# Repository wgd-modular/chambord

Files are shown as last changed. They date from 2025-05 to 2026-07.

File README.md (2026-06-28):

# Chambord

Chambord is a eurorack module, using the RP2040 or 2350 to implement an
8-channel trigger-in drum sampler.

The 8 channels are laid out **top to bottom = channel 1 to 8**. Each channel
has a trigger input jack and a bicolor (red/green) LED. There is one encoder
(turn + press) and one CV input.

# How to use it

There are only two controls: **turn** the encoder and **press** the encoder.

## Turning the encoder

What turning does depends on the current "page". You step through the pages by
**short-pressing** the encoder:

```
press        press         press        press
SELECT  -->  SAMPLE  -->  VOLUME  -->  PITCH  --> (back to SELECT)
```

- **SELECT** (start here): turn to choose the channel you want to work on.
- **SAMPLE**: turn to change the sample on the selected channel. Each channel
  has 4 samples (banks A–D); turning steps between them.
- **VOLUME**: turn to change the volume of the selected channel.
- **PITCH**: turn to change the pitch of the selected channel.

A short press always advances to the next page and wraps back to SELECT.

## Reading the LEDs

While you're editing, only the **selected channel's** LED lights, colour-coded
by page (green = choosing a thing, amber = setting an amount):

| LED | Page |
|---|---|
| green steady | SELECT  (turn to pick the channel) |
| green blinking | SAMPLE  (turn to change the sample) |
| amber steady | VOLUME  (turn to change the volume) |
| amber blinking | PITCH (turn to change the pitch) |

You'll also hear sample/volume/pitch changes as you turn.

## Screensaver / trigger activity

When you haven't touched the encoder for about **10 seconds**, the row switches
to a trigger-activity display: every channel flashes **green** when it gets a
trigger. Touch the encoder and it goes back to showing what you're editing.
(This keeps trigger flashes from distracting you while you work.)

## CV input

**Long-press** the encoder (hold ~3/4 second) to assign the CV input to the
**volume** of the currently selected channel. Long-press again on the same
channel to turn CV off.

## Settings are saved

Your per-channel sample and pitch choices (and the CV assignment) are saved
automatically to flash a moment after you stop adjusting, and restored on the
next power-up. Saving only happens while nothing is sounding, so it never
interrupts playback.

## If the encoder turns the wrong way

Open `firmware/Pikobeats/Pikobeats.ino` and change `ENCODER_DIR` from `1` to
`-1` (near the top), then rebuild.

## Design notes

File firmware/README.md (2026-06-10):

# Firmware 

This directory contains a number of variant firmware and support files for Chambord.

# Status

10.06.2026 - The 'trippy' uf2 is built with an rp2350 (pi pico 2). The led lighting may not suit, file an issue :)

20.06.2025 - The current status is beta for Pikobeats. An initial uf2 is included for testing. Angular jungle set.

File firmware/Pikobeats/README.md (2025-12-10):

## piko beats

In order to render cleanly, using the timer driven method curently employed:
Pico2, optimize -O3, overclock to 276mHz

The samples are, still, prepared by the wav2header utility (windows, runs fine with wine64). The naming is a bit odd, still.

There are four sets, a, b, c, d each of which have 8 files. so it's a1-instrument ( descriptive text ). This should be improved.

a1-BD
b2-BD
c3-BD
d4-BD 

would yeild the bassdrum instruments on channel one.

A better naming would be something like
a-1
a-2
...
b-1
b-2
... etc.

This naming ordering would work fine with wav2header since the header in pikobeats just lists the samples in order, not by name.

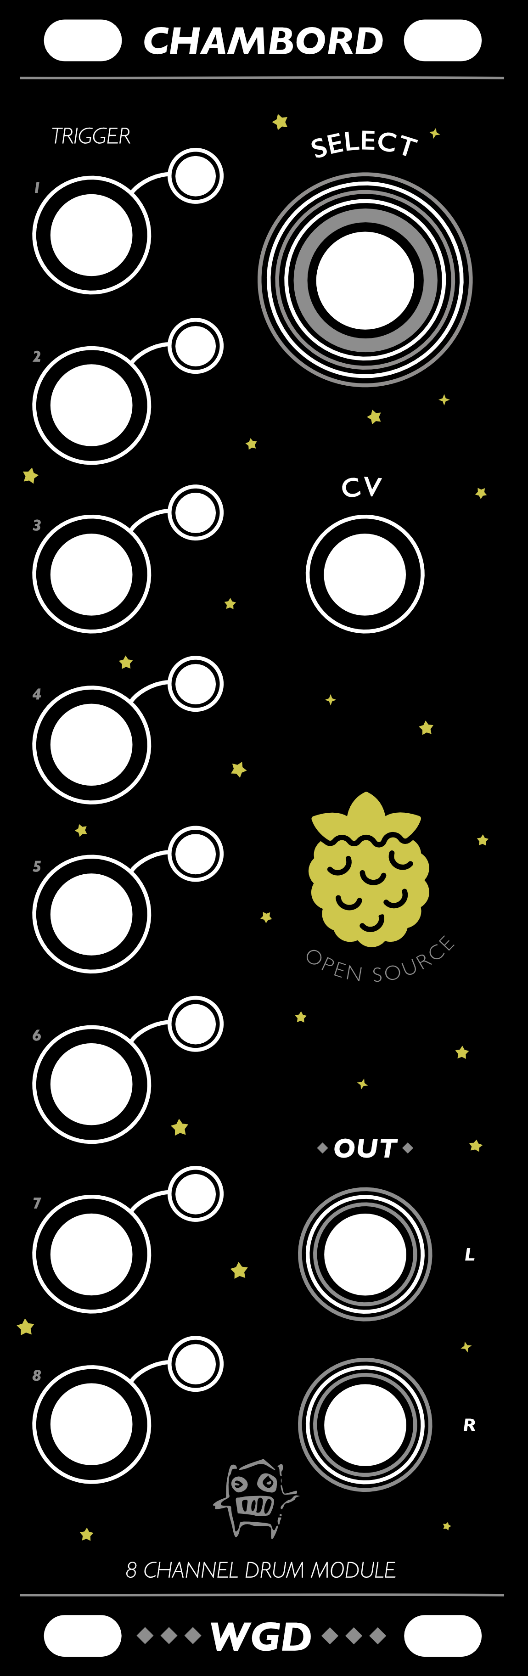
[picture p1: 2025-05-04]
design-resources/chambord.png

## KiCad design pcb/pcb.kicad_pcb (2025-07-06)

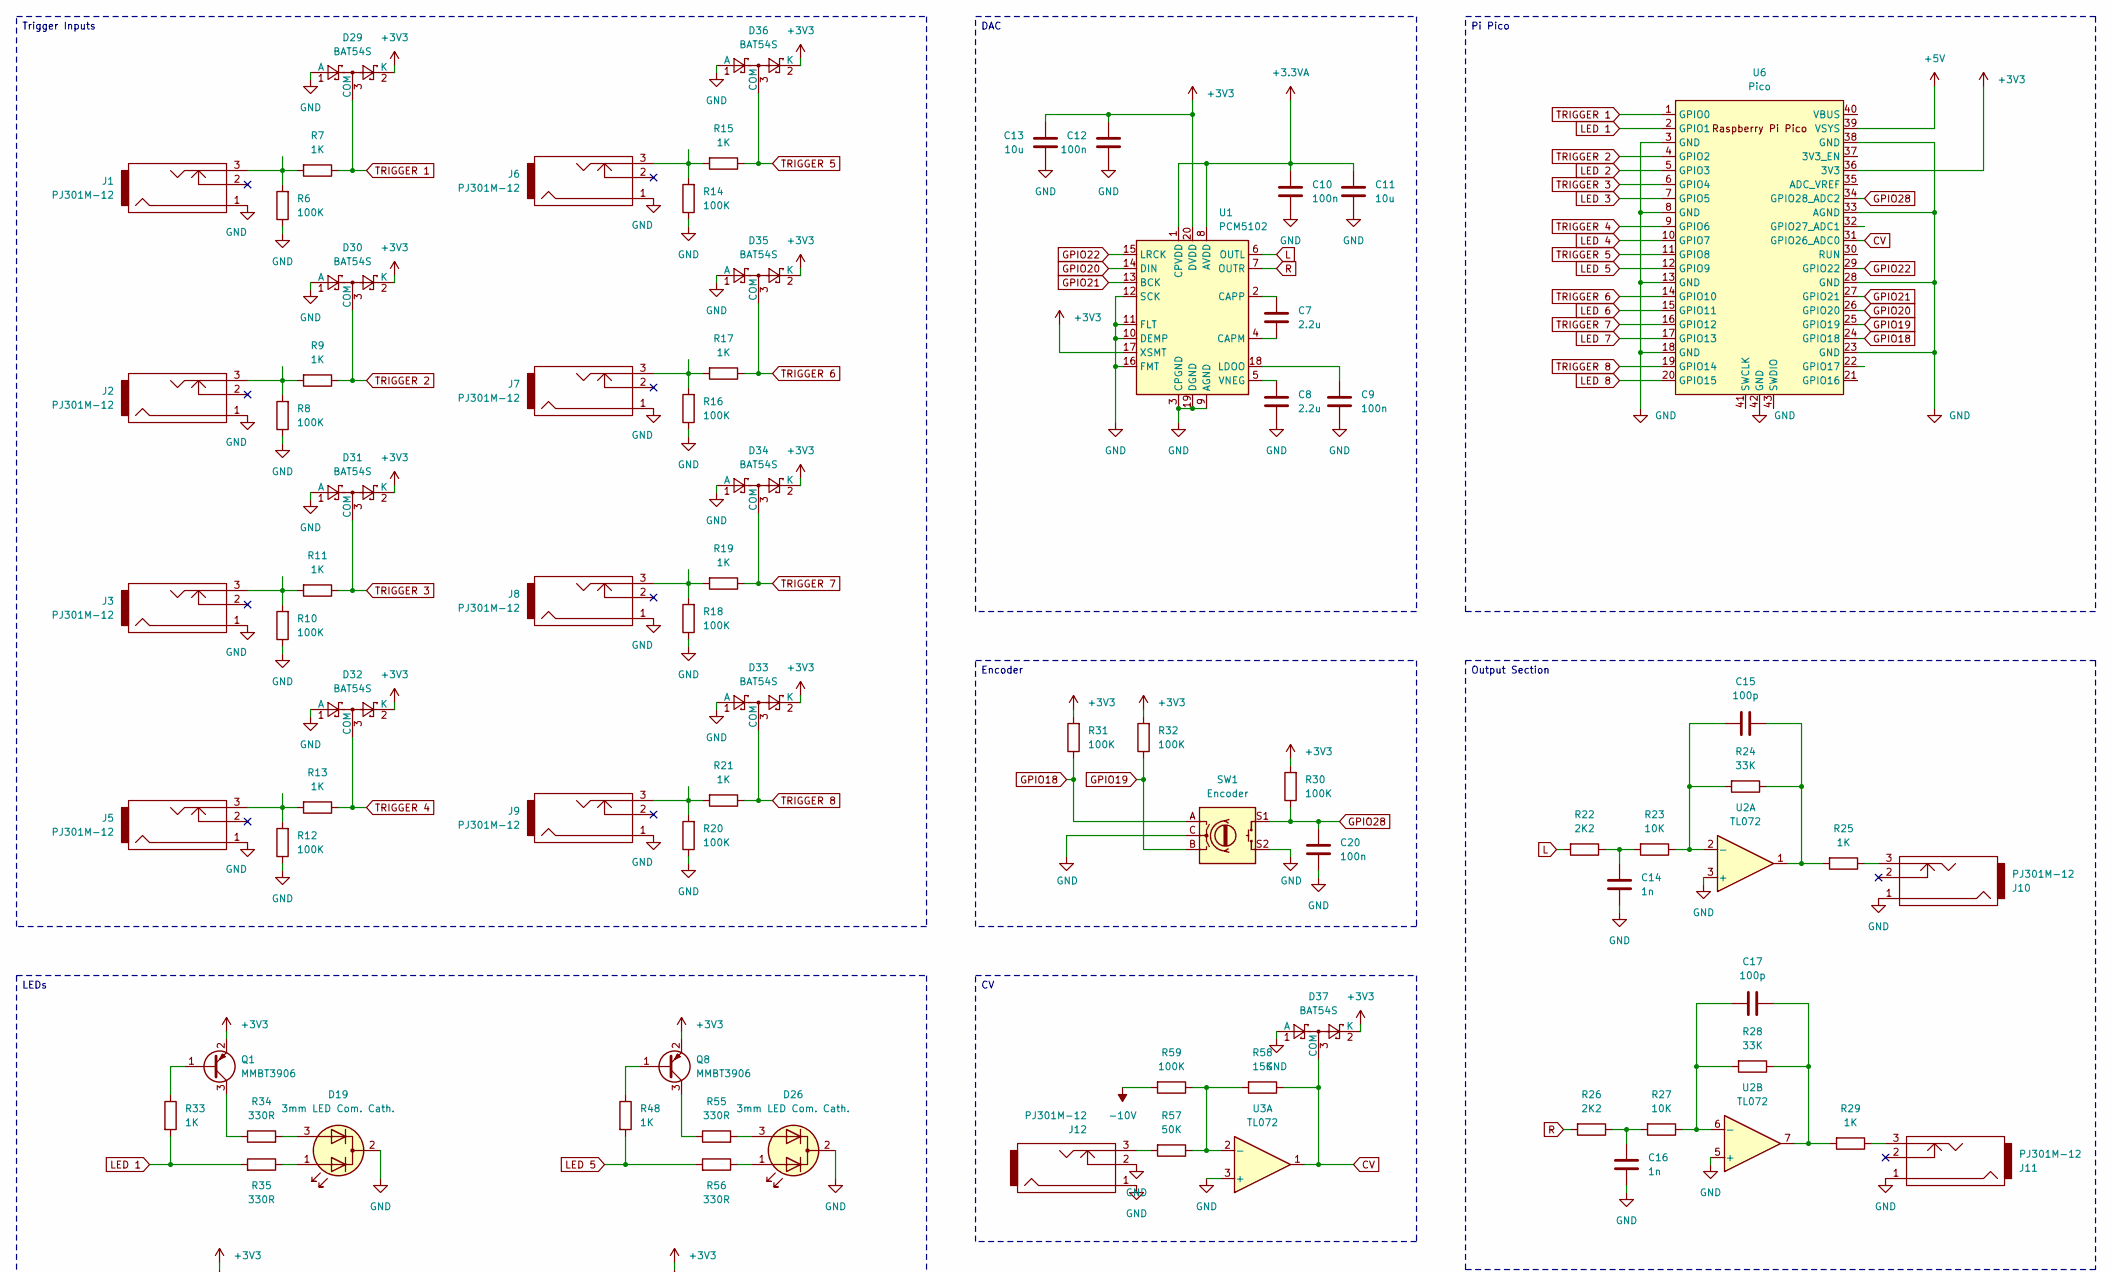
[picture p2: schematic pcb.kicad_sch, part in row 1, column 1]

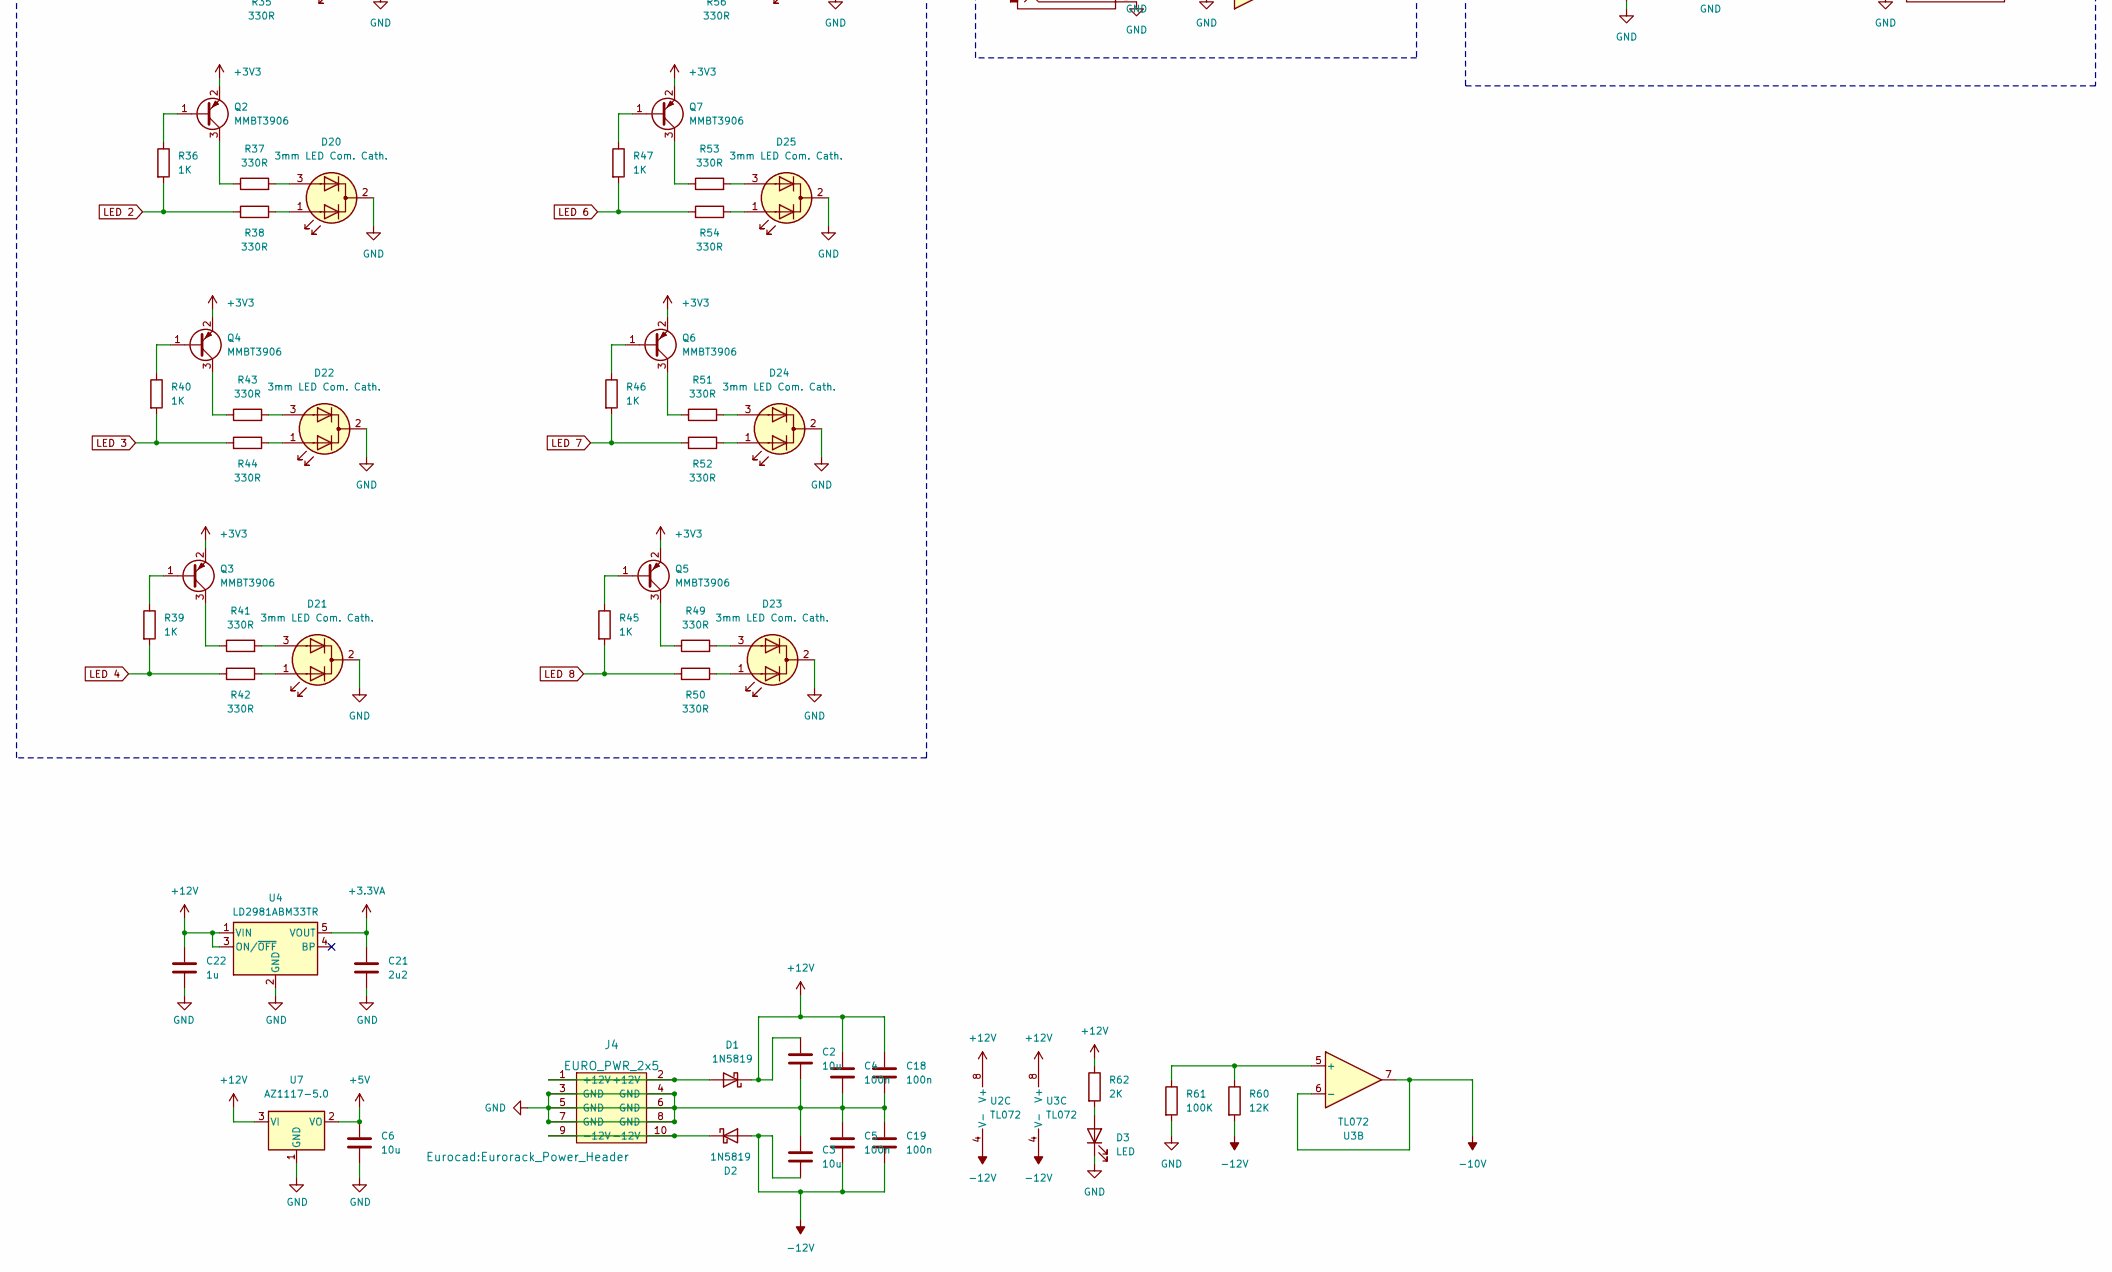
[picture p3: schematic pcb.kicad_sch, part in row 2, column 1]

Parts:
C2, C3, C6, C11, C13: 10u; C_0805_2012Metric
C4, C5, C9, C10, C12, C18, C19, C20: 100n; C_0603_1608Metric
C7, C8: 2.2u; C_0805_2012Metric
C14, C16: 1n; C_0603_1608Metric
C15, C17: 100p; C_0603_1608Metric
C21: 2u2; C_0805_2012Metric
C22: 1u; C_0805_2012Metric
D1, D2: 1N5819; D_SOD-123
D3: LED; LED_0603_1608Metric
D19, D20, D21, D22, D23, D24, D25, D26: 3mm LED Com. Cath.; LED_D3.0mm-3
D29, D30, D31, D32, D33, D34, D35, D36, D37: BAT54S; SOT-23; JLC C7420333
J1, J2, J3, J5, J6, J7, J8, J9, J10, J11, J12: PJ301M-12
J4: EURO_PWR_2x5; Eurorack_Power_Header
Q1, Q2, Q3, Q4, Q5, Q6, Q7, Q8: MMBT3906; SOT-23
R6, R8, R10, R12, R14, R16, R18, R20, R30, R31, R32, R59, R61: 100K; R_0603_1608Metric
R7, R9, R11, R13, R15, R17, R19, R21, R25, R29, R33, R36, R39, R40, R45, R46, R47, R48: 1K; R_0603_1608Metric
R22, R26: 2K2; R_0603_1608Metric
R23, R27: 10K; R_0603_1608Metric
R24, R28: 33K; R_0603_1608Metric
R34, R35, R37, R38, R41, R42, R43, R44, R49, R50, R51, R52, R53, R54, R55, R56: 330R; R_0603_1608Metric
R57: 50K; R_0603_1608Metric
R58: 15K; R_0603_1608Metric
R60: 12K; R_0603_1608Metric
R62: 2K; R_0603_1608Metric
SW1: Encoder; RotaryEncoder_Alps_EC11E-Switch_Vertical_H20mm
U1: PCM5102; TSSOP-20_4.4x6.5mm_P0.65mm
U2, U3: TL072; SOIC-8_3.9x4.9mm_P1.27mm
U4: LD2981ABM33TR; SOT-23-5
U6: Pico; RaspberryPi_Pico_Common_THT
U7: AZ1117-5.0; SOT-223-3_TabPin2

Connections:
+3.3VA: C10.1, C11.1, C21.1, U1.1 (CPVDD), U1.8 (AVDD), U4.5 (VOUT)
+3V3: C12.1, C13.1, D29.2 (K), D30.2 (K), D31.2 (K), D32.2 (K), D33.2 (K), D34.2 (K), D35.2 (K), D36.2 (K), D37.2 (K), Q1.2 (E), Q2.2 (E), Q3.2 (E), Q4.2 (E), Q5.2 (E), Q6.2 (E), Q7.2 (E), Q8.2 (E), R30.2, R31.2, R32.2, U1.17 (XSMT), U1.20 (DVDD), U6.36 (3V3)
+5V: C6.1, U6.39 (VSYS), U7.2 (VO)
+12V: C2.1, C4.1, C18.1, C22.1, D1.1 (K), R62.1, U2.8 (V+), U3.8 (V+), U4.1 (VIN), U4.3 (ON/~OFF), U7.3 (VI)
-10V: R59.2, U3.6 (-), U3.7
-12V: C3.2, C5.2, C19.2, D2.2 (A), R60.2, U2.4 (V-), U3.4 (V-)
CV: D37.3 (COM), R58.1, U3.1, U6.31 (GPIO26_ADC0)
GND: C2.2, C3.1, C4.2, C5.1, C6.2, C8.2, C9.2, C10.2, C11.2, C12.2, C13.2, C14.2, C16.2, C18.2, C19.1, C20.2, C21.2, C22.2, D3.1 (K), D19.2 (K), D20.2 (K), D21.2 (K), D22.2 (K), D23.2 (K), D24.2 (K), D25.2 (K), D26.2 (K), D29.1 (A), D30.1 (A), D31.1 (A), D32.1 (A), D33.1 (A), D34.1 (A), D35.1 (A), D36.1 (A), D37.1 (A), J1.1, J2.1, J3.1, J4.3 (GND), J4.4 (GND), J4.5 (GND), J4.6 (GND), J4.7 (GND), J4.8 (GND), J5.1, J6.1, J7.1, J8.1, J9.1, J10.1, J11.1, J12.1, J12.2, R6.1, R8.1, R10.1, R12.1, R14.1, R16.1, R18.1, R20.1, R61.2, SW1.C, SW1.S2, U1.3 (CPGND), U1.9 (AGND), U1.10 (DEMP), U1.11 (FLT), U1.12 (SCK), U1.16 (FMT), U1.19 (DGND), U2.3 (+), U2.5 (+), U3.3 (+), U4.2 (GND), U6.3 (GND), U6.8 (GND), U6.13 (GND), U6.18 (GND), U6.23 (GND), U6.28 (GND), U6.33 (AGND), U6.38 (GND), U6.42 (GND), U7.1 (GND)
GPIO18: R31.1, SW1.A, U6.24 (GPIO18)
GPIO19: R32.1, SW1.B, U6.25 (GPIO19)
GPIO20: U1.14 (DIN), U6.26 (GPIO20)
GPIO21: U1.13 (BCK), U6.27 (GPIO21)
GPIO22: U1.15 (LRCK), U6.29 (GPIO22)
GPIO28: C20.1, R30.1, SW1.S1, U6.34 (GPIO28_ADC2)
L: R22.2, U1.6 (OUTL)
LED 1: R33.2, R35.2, U6.2 (GPIO1)
LED 2: R36.2, R38.2, U6.5 (GPIO3)
LED 3: R40.2, R44.2, U6.7 (GPIO5)
LED 4: R39.2, R42.2, U6.10 (GPIO7)
LED 5: R48.2, R56.2, U6.12 (GPIO9)
LED 6: R47.2, R54.2, U6.15 (GPIO11)
LED 7: R46.2, R52.2, U6.17 (GPIO13)
LED 8: R45.2, R50.2, U6.20 (GPIO15)
unnamed: C14.1, R22.1, R23.2
unnamed: C15.2, R24.1, R25.2, U2.1
unnamed: C16.1, R26.1, R27.2
unnamed: C17.2, R28.1, R29.2, U2.7
unnamed: D1.2 (A), J4.1 (+12V), J4.2 (+12V)
unnamed: D2.1 (K), J4.9 (-12V), J4.10 (-12V)
unnamed: D3.2 (A), R62.2
unnamed: D19.1 (A1), R35.1
unnamed: D19.3 (A2), R34.2
unnamed: D20.1 (A1), R38.1
unnamed: D20.3 (A2), R37.2
unnamed: D21.1 (A1), R42.1
unnamed: D21.3 (A2), R41.2
unnamed: D22.1 (A1), R44.1
unnamed: D22.3 (A2), R43.2
unnamed: D23.1 (A1), R50.1
unnamed: D23.3 (A2), R49.2
unnamed: D24.1 (A1), R52.1
unnamed: D24.3 (A2), R51.2
unnamed: D25.1 (A1), R54.1
unnamed: D25.3 (A2), R53.2
unnamed: D26.1 (A1), R56.1
unnamed: D26.3 (A2), R55.2
unnamed: J1.3, R6.2, R7.2
unnamed: J2.3, R8.2, R9.2
unnamed: J3.3, R10.2, R11.2
unnamed: J5.3, R12.2, R13.2
unnamed: J6.3, R14.2, R15.2
unnamed: J7.3, R16.2, R17.2
unnamed: J8.3, R18.2, R19.2
unnamed: J9.3, R20.2, R21.2
unnamed: J10.3, R25.1
unnamed: J11.3, R29.1
unnamed: J12.3, R57.2
unnamed: Q1.1 (B), R33.1
unnamed: Q1.3 (C), R34.1
unnamed: Q2.1 (B), R36.1
unnamed: Q2.3 (C), R37.1
unnamed: Q3.1 (B), R39.1
unnamed: Q3.3 (C), R41.1
unnamed: Q4.1 (B), R40.1
unnamed: Q4.3 (C), R43.1
unnamed: Q5.1 (B), R45.1
unnamed: Q5.3 (C), R49.1
unnamed: Q6.1 (B), R46.1
unnamed: Q6.3 (C), R51.1
unnamed: Q7.1 (B), R47.1
unnamed: Q7.3 (C), R53.1
unnamed: Q8.1 (B), R48.1
unnamed: Q8.3 (C), R55.1
unnamed: C7.2, U1.4 (CAPM)
unnamed: C7.1, U1.2 (CAPP)
unnamed: C9.1, U1.18 (LDOO)
unnamed: C8.1, U1.5 (VNEG)
unnamed: C15.1, R23.1, R24.2, U2.2 (-)
unnamed: C17.1, R27.1, R28.2, U2.6 (-)
unnamed: R57.1, R58.2, R59.1, U3.2 (-)
unnamed: R60.1, R61.1, U3.5 (+)
R: R26.2, U1.7 (OUTR)
TRIGGER 1: D29.3 (COM), R7.1, U6.1 (GPIO0)
TRIGGER 2: D30.3 (COM), R9.1, U6.4 (GPIO2)
TRIGGER 3: D31.3 (COM), R11.1, U6.6 (GPIO4)
TRIGGER 4: D32.3 (COM), R13.1, U6.9 (GPIO6)
TRIGGER 5: D36.3 (COM), R15.1, U6.11 (GPIO8)
TRIGGER 6: D35.3 (COM), R17.1, U6.14 (GPIO10)
TRIGGER 7: D34.3 (COM), R19.1, U6.16 (GPIO12)
TRIGGER 8: D33.3 (COM), R21.1, U6.19 (GPIO14)

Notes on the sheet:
Encoder
DAC
LEDs
Pi Pico
Trigger Inputs
Output Section

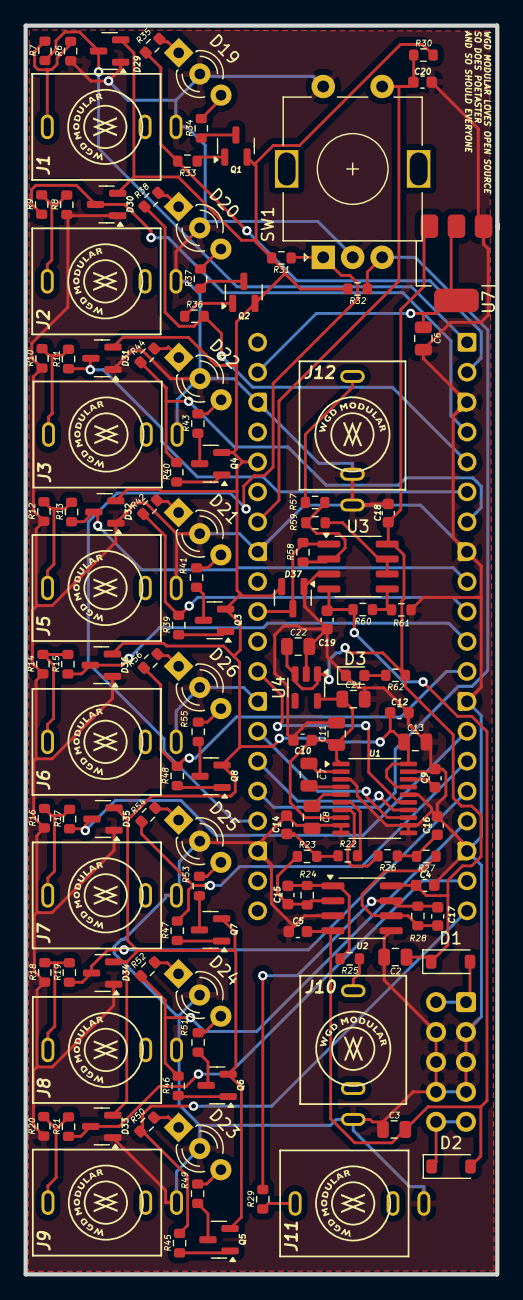
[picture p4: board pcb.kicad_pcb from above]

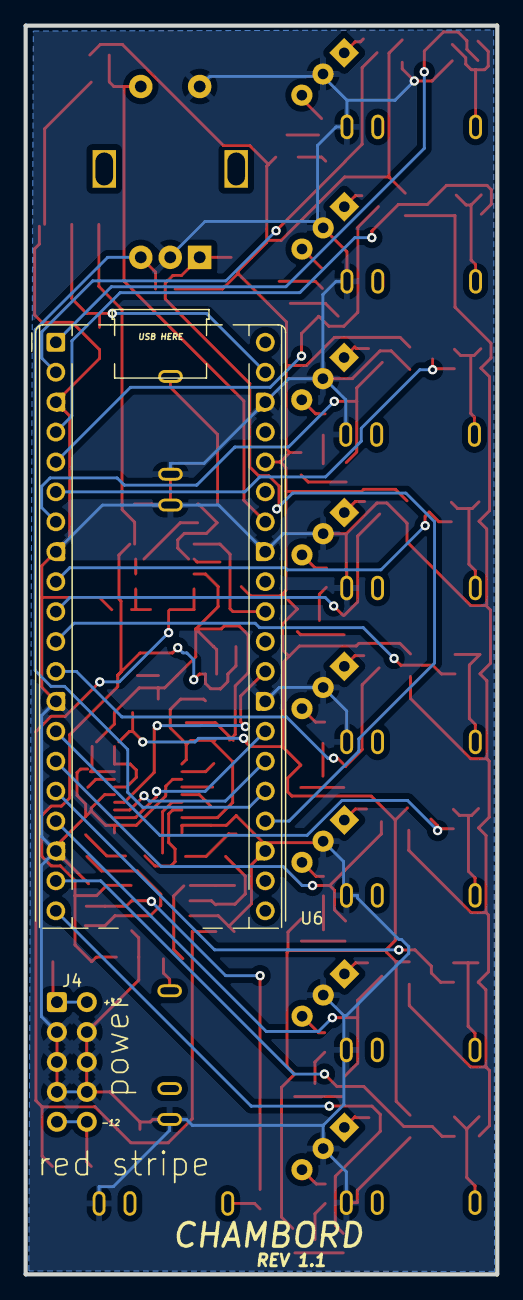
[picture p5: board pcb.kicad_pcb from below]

Board: 2 copper layers, 40.0 x 106.0 mm, 125 parts (2 on the bottom side), 90 nets.

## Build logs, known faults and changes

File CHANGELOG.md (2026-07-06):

# Changelog

## 1.0.0 (2026-07-01)

### Features

* rework audio engine, simplify UI, add CI ([d3c88b5](https://github.com/wgd-modular/chambord/commit/d3c88b5726d20f5539bd95611d42c632e766eb0f))
* rework audio engine, simplify UI, add CI ([da60962](https://github.com/wgd-modular/chambord/commit/da6096227d832539272b47c49966bcbeb733e541))

### Bug Fixes

* Allow rotational channel selection ([18fcced](https://github.com/wgd-modular/chambord/commit/18fccedee60266fa6a5453aa082c8b1f41a5744f))
* corrected uf2 ([98e2633](https://github.com/wgd-modular/chambord/commit/98e2633e7d3a1c4cf471b4a8414e017b1c8b5e8f))
* get all the basics running ([564b5db](https://github.com/wgd-modular/chambord/commit/564b5db0c58d85b13a0e121b2e7f20b510d59753))
* move DAC writes to 48khz timer and only do sample generation on request when dac has been writtern. ([0ea6d1c](https://github.com/wgd-modular/chambord/commit/0ea6d1c6be09060b37d975405fbccce7a9ee2cff))
* move encoder processing and remove contention on leds to remove noise ([00241a3](https://github.com/wgd-modular/chambord/commit/00241a3001df9c9cd52b4fd3415baddb6ffa9bd3))
* move jack in led signal to timer. cv also on slow timer. ([21f0c8b](https://github.com/wgd-modular/chambord/commit/21f0c8b7639766c76f8883b62c31836081725064))
* new uf2 with latest timer code ([514b767](https://github.com/wgd-modular/chambord/commit/514b7678cf0143d4c2cfdfc8f3cfe787f7a16f79))
* remove core idling since it can crash. ([1852d89](https://github.com/wgd-modular/chambord/commit/1852d89e810b191ad4a3e83d04a00b6cf68b015c))
* set to 44100 kHz for pitch correct play, up buffer lengths ([c2309d1](https://github.com/wgd-modular/chambord/commit/c2309d1a34663f6960478cda913241d967c42cab))

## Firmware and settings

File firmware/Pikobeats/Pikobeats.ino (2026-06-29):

/* Copyright 2025 Mark Washeim
  Author: Mark Washeim <blueprint@poetaster.de>

  This program is a derivative of one made by Rich Heslip, 2023,
  The euclidean bits are derivatives of code from bastl instruments.

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
  See http://creativecommons.org/licenses/MIT/ for more information.

  -----------------------------------------------------------------------------


  // sample player inspired by Jan Ostman's ESP8266 drum machine http://janostman.wordpress.com

  samples for beatbox from:
  giddster ( https://freesound.org/people/giddster/ )
  AlienXXX ( https://freesound.org/people/AlienXXX/

  The euclid code originates at:
  https://github.com/bastl-instruments/one-chip-modules/blob/master/EUCLID/EUCLID.ino

*/

bool debug = false;

#include <Arduino.h>
#include "stdio.h"
#include "pico/stdlib.h"
#include "hardware/gpio.h"
#include "hardware/sync.h"
#include "hardware/structs/ioqspi.h"
#include "hardware/structs/sio.h"

#include "io.h"
#include "euclid.h"
#include "filter.h"

#include <math.h>     // tanhf for the output soft-clip
#include <EEPROM.h>   // flash-backed settings persistence

// we have 8 voices that can play any sample when triggered
// this structure holds the settings for each voice
// 80s only to 20, jungle to 29
// we use a header per sample set
//
// Pick the sound kit at compile time. The CI builds one firmware per kit by
// passing e.g. -DCHAMBORD_KIT_80S ; locally, define one of these (or leave the
// default trippy). Each kit header defines voice_t/voice[] and pulls in its
// own samples. ("not ready" kits world/beatbox/bbox have no sample data.)
#if   defined(CHAMBORD_KIT_80S)
  #include "80s.h"
#elif defined(CHAMBORD_KIT_ANGULARJ)
  #include "angularj.h"
#elif defined(CHAMBORD_KIT_MIX)
  #include "mix.h"
#elif defined(CHAMBORD_KIT_TEKKE)
  #include "tekke.h"
#elif defined(CHAMBORD_KIT_ACOUSTIC3)
  #include "acoustic3.h"
#else
  #include "trippy.h"
#endif
// we can have an arbitrary number of samples but you will run out of memory at some point
// sound sample files are 22khz 16 bit signed PCM format - see the sample include files for examples
// you can change the sample rate to whatever you want but most testing was done at 22khz. 44khz probably works but not much testing was done
// use the wave2header22khz.exe utility to automagically batch convert all the .wav files in a directory into the required header files
// put your 22khz or 44khz PCM wav files in a sample subdirectory with a copy of the utility, run the utility and it will generate all the required header files
// wave2header creates a header file containing the signed PCM values for each sample - note that it may change the name of the file if required to make it "c friendly"
// wave2header also creates sampledefs.h which is an array of structures containing information about each sample file
// the samples are arranged in alphabetical order to facilitate grouping samples by name - you can manually edit this file to change the order of the samples as needed
// sampledefs.h contains other information not used by this program e.g. the name of the sample file - I wrote it for another project
// wave2header also creates "samples.h" which #includes all the generated header files


#define NUM_SAMPLES (sizeof(sample)/sizeof(sample_t))

// What turning the encoder does. Press the encoder to step through these
// for the currently selected channel: select -> sample -> volume -> pitch.
enum {
  MODE_SELECT = 0, // turn = choose channel (1-8)
  MODE_SAMPLE,     // turn = change the sample of the selected channel
  MODE_VOLUME,     // turn = change the volume of the selected channel
  MODE_PITCH,      // turn = change the pitch of the selected channel
  MODE_COUNT
};

int display_mode = MODE_SELECT;

// Encoder direction. 1 = normal, -1 = inverted. The CI builds both variants by
// passing -DCHAMBORD_ENC_DIR=... ; to change it locally edit the default below.
#ifndef CHAMBORD_ENC_DIR
#define CHAMBORD_ENC_DIR 1
#endif
const int ENCODER_DIR = CHAMBORD_ENC_DIR;

// on the long ec11 these are swapped A 19, B 18
const int encoderA_pin = 18;
const int encoderB_pin = 19;
const int encoderSW_pin = 28;

#define DOUBLE_CLICK_THRESHOLD 400 
// encoder
#include <RotaryEncoder.h>
RotaryEncoder encoder(encoderB_pin, encoderA_pin, RotaryEncoder::LatchMode::FOUR3);

void __not_in_flash_func(checkEncoderPosition)() {
  encoder.tick();   // call tick() to check the state.
}

// DAC code, approach from mozzi

#include <I2S.h>
// GPIO pin numbers
#define pBCLK 21
#define pWS (pBCLK+1)
#define pDOUT 20

I2S DAC(OUTPUT);

static void startAudio() {
  DAC.setBCLK(pBCLK);
  DAC.setDATA(pDOUT);
  DAC.setBitsPerSample(16);
  DAC.setBuffers(4, 256, 0);
  DAC.begin(44100);
}

static void stopAudio() {
  DAC.end();
}
inline bool canBufferAudioOutput() {
  return (DAC.availableForWrite());
}

// these are irq timers for handling led signals
#include "timers.h"



// encoder button
#include <Bounce2.h>
Bounce2::Button enc_button = Bounce2::Button();

// additions
#include <Wire.h>

volatile int clk_display;
uint32_t clk_sync_last;

// input clk tracking
volatile int clk_state_last; // track the CLOCKIN pin state.

int clk_state = 0;
int clk_hits = 0;
uint32_t clk_sync_ms = 0;
bool sync = false; // used to detect if we have input sync


// begin hardware definitions
const int key_pins[] = { 0, 2, 4, 6, 8, 10, 12, 14 };
const int led_pins[] = { 1, 3, 5, 7, 9, 11, 13, 15 };


// variables for UI state management
int encoder_pos_last = 0;
int encoder_delta = 0;
uint32_t encoder_push_millis;
uint32_t step_push_millis;

// currently not used
int step_push = -1;
bool step_edited = false;
char seq_info[11];  // 10 chars + nul FIXME

bool encoder_held = false;

uint8_t display_repeats = 0;
uint8_t display_vol = 100;
uint8_t display_pitch = 50;
String display_pat;


// END additions

// from pikocore filter
uint8_t filter_fc = LPF_MAX + 10;
uint8_t hpf_fc = 0;
uint8_t filter_q = 0;

int16_t CV_last;

//#define MONITOR_CPU  // define to monitor Core 2 CPU usage on pin CPU_USE

// last time btn_one release
unsigned long btnOneLastTime;
int cv_track = 42; // used to assign a track CV modulation set out of bounds to start


// sample and debounce
// scan input jacks
bool scanbuttons(void)
{
  bool pressed;
  for (int i = 0; i < NUM_BUTTONS; ++i) {
    switch (i) { // sample gate inputs
      case 0:
        pressed = digitalRead(BUTTON0); // active low key inputs
        break;
      case 1:
        pressed = digitalRead(BUTTON1);
        break;
      case 2:
        pressed = digitalRead(BUTTON2);
        break;
      case 3:
        pressed = digitalRead(BUTTON3);
        break;
      case 4:
        pressed = digitalRead(BUTTON4);
        break;
      case 5:
        pressed = digitalRead(BUTTON5);
        break;
      case 6:
        pressed = digitalRead(BUTTON6);
        break;
      case 7:
        pressed = digitalRead(BUTTON7);
        break;
    }

    if (pressed) {
      if (debouncecnt[i] <= 3) ++debouncecnt[i];
      if (debouncecnt[i] == 2) { // trigger on second sample of key active
        button[i] = 1;
      }
    }
    else {
      debouncecnt[i] = 0;
      button[i] = 0;
    }
  }
  if (pressed) return true;
  else return false;
}


// include here to avoid forward references - I'm lazy :)
// this is the main class for generating output samples using the internal sequencer.

#include "seq.h"

// ---------------------------------------------------------------------------
// Audio mixing: precomputed per-voice gain + attack ramp (anti-click)
// ---------------------------------------------------------------------------
#define RAMP_LEN 48                 // ~1.1ms attack at 44.1kHz to kill retrigger clicks
int32_t  voice_gain[NTRACKS];       // Q15 gain (level/1000) precomputed so the mix loop has no divide
uint16_t voice_ramp[NTRACKS];       // attack ramp counter per track, counts up to RAMP_LEN

// set a track level (0-1000) and recompute its Q15 mix gain
inline void setLevel(int track, int level) {
  if (level < 0) level = 0;
  if (level > 1000) level = 1000;
  voice[track].level = level;
  voice_gain[track] = ((int32_t)level * 32768) / 1000;
}

// ---------------------------------------------------------------------------
// Settings persistence to flash (survives power cycle)
// stored: per-track sample + pitch, plus CV/selected track
// ---------------------------------------------------------------------------
#define EE_MAGIC 0xB4
#define EE_SIZE  256
struct persist_t {
  uint8_t  magic;
  uint8_t  cv_track;
  uint8_t  current_track;
  int16_t  sample[NTRACKS];
  uint16_t incr[NTRACKS];
  int16_t  level[NTRACKS];
};

bool     settings_dirty = false;
uint32_t settings_change_ms = 0;
inline void markDirty() { settings_dirty = true; settings_change_ms = millis(); }

void loadSettings() {
  persist_t p;
  EEPROM.get(0, p);
  if (p.magic != EE_MAGIC) return;            // nothing valid stored yet
  cv_track = p.cv_track;
  current_track = p.current_track % NTRACKS;
  for (int t = 0; t < NTRACKS; ++t) {
    if (p.sample[t] >= 0 && p.sample[t] < (int)NUM_SAMPLES) voice[t].sample = p.sample[t];
    voice[t].sampleincrement = constrain(p.incr[t], 2048, 8192);
    setLevel(t, p.level[t]);
  }
}

void saveSettings() {
  persist_t p;
  p.magic = EE_MAGIC;
  p.cv_track = cv_track;
  p.current_track = current_track;
  for (int t = 0; t < NTRACKS; ++t) {
    p.sample[t] = voice[t].sample;
    p.incr[t]   = voice[t].sampleincrement;
    p.level[t]  = voice[t].level;
  }
  EEPROM.put(0, p);
  EEPROM.commit();   // idles core1 internally during the flash erase/program
}

// ---------------------------------------------------------------------------
// Unified LED feedback engine
// Each LED is a single GPIO over a dual-colour part: GPIO low = red (floor),
// high = green, and a duty cycle in between = amber. ledRender() does software
// PWM from led_duty[]; updateUI() sets led_duty[] from the current UI state.
// ---------------------------------------------------------------------------
#define LED_LEVELS 8        // PWM steps -> 1ms tick gives ~125Hz refresh
#define LED_RED    0        // GPIO mostly low  -> red (also the idle floor colour)
#define LED_AMBER  4        // ~50% duty        -> amber
#define LED_GREEN  8        // GPIO high        -> green

volatile uint8_t led_duty[8] = {0};
volatile uint8_t led_phase = 0;

// software PWM, called every 1ms from the ISR timer (kept in RAM so it never
// waits on the flash bus that the audio core is reading samples from)
void __not_in_flash_func(ledRender)() {
  uint8_t ph = led_phase;
  for (int i = 0; i < 8; ++i) {
    digitalWrite(led[i], (led_duty[i] > ph) ? HIGH : LOW);
  }
  led_phase = (ph + 1) % LED_LEVELS;
}

// When the encoder hasn't been touched for this long, the row turns into a
// trigger-activity display ("screensaver"). While you ARE editing, the row
// shows only the selected channel's page so nothing distracts you.
#define SCREENSAVER_MS 3000
uint32_t ui_activity_ms = 0;

// Recompute per-channel LED colours. While editing, feedback lives only on the
// selected channel's own LED, colour-coded by page (green = choosing a thing,
// amber = setting an amount):
//   green steady   = SELECT  (turn to pick the channel)
//   green blinking = SAMPLE  (turn to change the sample)
//   amber steady   = VOLUME  (turn to change the volume)
//   amber blinking = PITCH   (turn to change the pitch)
// After SCREENSAVER_MS idle, every channel flashes green on a trigger instead.
// Throttled by the caller (~5ms) so it doesn't hog the flash bus.
void updateUI() {
  uint32_t now = millis();
  bool blink = (now / 150) & 1; // ~3 Hz
  bool screensaver = (now - ui_activity_ms) > SCREENSAVER_MS;

  for (int i = 0; i < 8; ++i) {
    uint8_t d = LED_RED; // idle floor

    if (screensaver) {
      if (voice[i].isPlaying) d = LED_GREEN;          // trigger-activity display
    } else if (i == current_track) {
      switch (display_mode) {
        case MODE_SELECT: d = LED_GREEN;                  break; // green steady
        case MODE_SAMPLE: d = blink ? LED_GREEN : LED_RED; break; // green blink
        case MODE_VOLUME: d = LED_AMBER;                  break; // amber steady
        case MODE_PITCH:  d = blink ? LED_AMBER : LED_RED; break; // amber blink
      }
    }
    led_duty[i] = d;
  }
}

#define DISPLAY_TIME 2000 // time in ms to display numbers on LEDS
int32_t display_timer;

// show a number in binary on the LEDs
void display_value(int16_t value) {
  for (int i = 7; i >= 0; i--) { // NOPE + 1 can loop this way because port assignments are sequential
    digitalWrite(led[i], value & 1);
    value = value >> 1;
  }
  display_timer = millis();
}

// rotate trigger pattern
uint16_t rightRotate(int shift, uint16_t value, uint8_t pattern_length) {
  uint16_t mask = ((1 << pattern_length) - 1);
  value &= mask;
  return ((value >> shift) | (value << (pattern_length - shift))) & mask;
}



// main core setup
void setup() {
  // set clock speed as in picokore
  //set_sys_clock_khz(264000, true); don't do this :)

  if (debug) Serial.begin(57600);

  // setup timers
  if (ITimer3.attachInterruptInterval(HW_TIMER_INTERVAL_MS * 1000, TimerHandler)) {
    if (debug) Serial.print(F("Starting ITimer1 OK, millis() = "));
    if (debug) Serial.println(millis());
    timersUp = true;
  } else {
    if (debug) Serial.println(F("Can't set ITimer1. Select another freq. or timer"));
    timersUp = false;
  }
  analogReadResolution(10);

  // Audio is rendered free-running on core1 and paced by the I2S DMA buffer
  // (DAC.write blocks when full), so no dedicated audio-rate timer is needed.

  // single LED software-PWM renderer (replaces the old b2/b5/b7/b10 handlers)
  ISR_timer.setInterval(1L, ledRender);


  if (debug) Serial.flush();


  // ENCODER
  pinMode(encoderA_pin, INPUT_PULLUP);
  pinMode(encoderB_pin, INPUT_PULLUP);
  attachInterrupt(digitalPinToInterrupt(encoderA_pin), checkEncoderPosition, CHANGE);
  attachInterrupt(digitalPinToInterrupt(encoderB_pin), checkEncoderPosition, CHANGE);
  // Encoder button
  
  enc_button.attach( SHIFTBUTTON, INPUT ); // USE EXTERNAL PULL-UP
  enc_button.interval(5); // 5ms debounce
  enc_button.setPressedState(LOW);

#ifdef MONITOR_CPU
  pinMode(CPU_USE, OUTPUT); // for monitoring CPU usage
#endif

  pinMode(BUTTON0, INPUT); // jack inputs
  pinMode(BUTTON1, INPUT);
  pinMode(BUTTON2, INPUT);
  pinMode(BUTTON3, INPUT);
  pinMode(BUTTON4, INPUT);
  pinMode(BUTTON5, INPUT);
  pinMode(BUTTON6, INPUT);
  pinMode(BUTTON7, INPUT);

  pinMode(LED0, OUTPUT);
  pinMode(LED1, OUTPUT);
  pinMode(LED2, OUTPUT);
  pinMode(LED3, OUTPUT);
  pinMode(LED4, OUTPUT);
  pinMode(LED5, OUTPUT);
  pinMode(LED6, OUTPUT);
  pinMode(LED7, OUTPUT);

  //pinMode(CLOCKOUT, OUTPUT);
  //pinMode(CLOCKIN, INPUT_PULLUP);

  pinMode(23, OUTPUT); // thi is to switch to PWM for power to avoid ripple noise
  digitalWrite(23, HIGH);


  //display_value(NUM_SAMPLES); // show number of samples on the display

  // init per-voice mix gains and ramps, then restore saved settings from flash
  for (int t = 0; t < NTRACKS; ++t) {
    setLevel(t, voice[t].level);
    voice_ramp[t] = RAMP_LEN;   // not ramping until first trigger
  }
  EEPROM.begin(EE_SIZE);
  loadSettings();

  startAudio();

}



// main core handles UI
void loop() {

  // timer
  uint32_t now = millis();
  scanbuttons(); // actually jack inputs

  // update the channel & play sample
  for (int i = 0; i < NTRACKS; ++i) { // scan all the trigger inputs (not the encoder button)
    if (button[i]) {
      //digitalWrite(led[i], 1); // we're doing the leds in timers.h
      voice[i].sampleindex = 0; // trigger sample for this track
      voice[i].isPlaying = true;
      voice_ramp[i] = 0; // restart attack ramp -> click-free retrigger
    }
  }

  encoder.tick();

  int encoder_pos = encoder.getPosition();
  if ( (encoder_pos != encoder_pos_last )) {
    encoder_delta = (encoder_pos - encoder_pos_last) * ENCODER_DIR;
  }

  // update encoder button state
  enc_button.update();

  // led updates on timer


  // use encoder and button
  if (encoder_delta) {
    ui_activity_ms = now; // wake the display out of screensaver

    // MODE_SELECT: turn to choose which channel (1-8) you're working on
    if ( display_mode == MODE_SELECT && ! enc_button.pressed() )  {
      // +8 keeps us in positive range for the modulo
      current_track = (current_track + encoder_delta + 8) % 8;
      // NOTE: selecting a channel no longer changes its volume (that caused clicks)
    }

    // MODE_SAMPLE: turn to change the sample of the selected channel
    if ( display_mode == MODE_SAMPLE ) {
      int result = voice[current_track].sample + (encoder_delta > 0 ? 8 : -8);
      if (debug) Serial.println(result);
      if (result >= 0 && result <= NUM_SAMPLES - 1) {
        voice[current_track].sample = result;
        voice_ramp[current_track] = 0; // re-attack to soften the swap if it's ringing
        markDirty();
      }
    }

    // MODE_VOLUME: turn to change the volume of the selected channel
    if ( display_mode == MODE_VOLUME ) {
      setLevel(current_track, voice[current_track].level + encoder_delta * 50);
      markDirty();
    }

    // MODE_PITCH: turn to change the pitch of the selected channel.
    // Unity = 4096 (1:12 fixed point); 2048..8192 spans one octave down..up.
    // 128/detent (~2.6 detents per semitone) - the old step of 10 was so tiny
    // (~0.24%/detent) that it felt like nothing happened.
    if ( display_mode == MODE_PITCH ) {
      int pitch_change = voice[current_track].sampleincrement + (encoder_delta * 128);
      pitch_change = constrain(pitch_change, 2048, 8192); // constrain returns a value, must assign
      pitch_change &= ~1;                                 // keep even -> no click
      voice[current_track].sampleincrement = pitch_change;
      markDirty();
    }
  }

  /// only set new pos last after use of the delta
  encoder_pos_last = encoder_pos;
  encoder_delta = 0;  // we've used it


  // Encoder button:
  //   short press  -> step turn-function: select -> pitch -> sample -> select
  //   long press (>700ms) -> toggle CV control of the selected channel's volume
  if (enc_button.rose()) {
    ui_activity_ms = now;
    btnOneLastTime = enc_button.previousDuration();
    if (btnOneLastTime > 700) {
      cv_track = (cv_track == current_track) ? 99 : current_track; // 99 = CV off
      markDirty();
    }
  } else if (enc_button.pressed() ) {
    ui_activity_ms = now;
    encoder_push_millis = now;
    display_mode = display_mode + 1;
    if ( display_mode >= MODE_COUNT) display_mode = MODE_SELECT;
  } else {
    encoder_push_millis = 0;
    encoder_held = false;
  }

  // CV input modulates the volume of the assigned channel (if any).
  // CV-driven volume is intentionally NOT persisted (would wear flash).
  if (cv_track < NTRACKS) {
    int16_t cvv = CV;
    if (cvv != CV_last) {
      setLevel(cv_track, constrain(cvv, 0, 350));
      CV_last = cvv;
    }
  }

  // Refresh UI + sample CV at ~200Hz (throttled so core0 doesn't starve the
  // audio core's flash reads -> this was a source of pops while turning).
  static uint32_t ui_last = 0;
  if (now - ui_last >= 5) {
    ui_last = now;
    CV = analogRead(A0);
    updateUI();
  }

  // Debounced auto-save, but only while nothing is sounding, so the brief
  // audio pause during the flash write happens in silence (no pop).
  if (settings_dirty && (now - settings_change_ms) > 1500) {
    bool anyPlaying = false;
    for (int i = 0; i < NTRACKS; ++i) if (voice[i].isPlaying) { anyPlaying = true; break; }
    if (!anyPlaying ) {
      saveSettings();
      settings_dirty = false;
    }
  }



  /*
     These are from the original scarp peakobeats
      if ( (encoder_pos != encoder_pos_last ) && display_mode == 1 ) {
        //uint8_t re = seq[i].trigger->getRepeats() + encoder_delta;
        seq[i].trigger->setRepeats(encoder_delta);
        display_repeats = seq[i].trigger->getRepeats();

      }
      // change volume on pot 1
      if (!potlock[1] && display_mode == 0) {
        int16_t level = (int16_t)(map(potvalue[1], POT_MIN, POT_MAX, 0, 1000));
        voice[current_track].level = level;
        display_vol = level / 10;
        // change sample volume level if pot has moved enough
      }
      if (!potlock[0] && display_mode == 1 ) {
        //filter_fc = potvalue[0] * (LPF_MAX + 10) / 4096;
        seq[i].fills = map(potvalue[0], POT_MIN, POT_MAX, 0, 16);
        seq[i].trigger->generateRandomSequence(seq[i].fills, 15);
        display_pat = (String) seq[i].trigger->textSequence;
      }

      // set track euclidean triggers if either pot has moved enough
      if (!potlock[1] && ! button[8] && display_mode == 1) {
        seq[i].fills = map(potvalue[1], POT_MIN, POT_MAX, 0, 16);
        seq[i].trigger->generateSequence(seq[i].fills, 15);
        seq[i].trigger->resetSequence(); // set to 0
        display_pat = (String) seq[i].trigger->textSequence;

      }
      //trig/retrig play
      if ( display_mode == 2 && i < 8 && voice[current_track].isPlaying == false) {
        voice[current_track].sampleindex = 0; // trigger sample for this track
        voice[current_track].isPlaying = true;
      }
  */
}



// second core setup
// second core dedicated to sample processing
void setup1() {
  delay (2000); // wait for main core to start up perhipherals
}
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

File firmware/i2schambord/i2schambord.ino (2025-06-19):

/*
  This example generates a square wave based tone at a specified frequency
  and sample rate. Then outputs the data using the I2S interface to a
  MAX08357 I2S Amp Breakout board.

  created 17 November 2016
  by Sandeep Mistry
  modified for RP2040 by Earle F. Philhower, III <earlephilhower@yahoo.com>


    bool setBCLK(pin_size_t pin);
    - This assigns two adjacent pins - the pin after this one (one greater)
      is the WS (word select) signal, which toggles before the sample for
      each channel is sent

    bool setDATA(pin_size_t pin);
    - Sets the DOUT pin, can be any valid GPIO pin
*/

#include <I2S.h>

// GPIO pin numbers
#define pBCLK 21
#define pWS (pBCLK+1)
#define pDOUT 20

I2S i2s(OUTPUT);

static void startAudio() {

  i2s.setBCLK(pBCLK);
  i2s.setDATA(pDOUT);
  i2s.setBitsPerSample(16);
  i2s.begin(48000);
}

static void stopAudio(){
  i2s.end();
}
inline bool canBufferAudioOutput() {
  return (i2s.availableForWrite());
}

const int frequency = 440; // frequency of square wave in Hz
const int amplitude = 500; // amplitude of square wave
const int sampleRate = 48000; // minimum for UDA1334A

const int halfWavelength = (sampleRate / frequency); // half wavelength of square wave

int16_t sample = amplitude; // current sample value
int count = 0;

void setup() {
  pinMode(3, OUTPUT);
  digitalWrite(3, 1);

  Serial.begin(115200);
  Serial.println("I2S simple tone");
  
  startAudio();
  

}

void loop() {
  if (count % halfWavelength == 0) {
    // invert the sample every half wavelength count multiple to generate square wave
    sample = -1 * sample;
    digitalWrite(3, 0);
  } else {
    digitalWrite(3,1);
  }

  // write the same sample twice, once for left and once for the right channel
  i2s.write(sample);
  i2s.write(sample);

  // increment the counter for the next sample
  count++;
}

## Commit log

2025-04-16 Start schematic
    [pcb.kicad_sch]
2025-04-17 Continue schematic
    [pcb.kicad_sch]
2025-04-17 Add LEDs, Triggers and CV in (closes #1)
    [pcb.kicad_sch]
2025-04-19 Replace OP-Amp and add GPIO input protection diodes for eventual clamping
    [pcb.kicad_sch]
2025-05-01 Implement feedback from Niek
    [pcb.kicad_sch]
2025-05-04 Rev 1
    [panel.kicad_pcb, pcb.kicad_pcb, pcb.kicad_sch]
2025-05-04 Move U7
    [pcb.kicad_pcb]
2025-06-13 Fix missing XSMT connection to 3V3
    [pcb.kicad_pcb, pcb.kicad_sch]
2025-06-19 Add: test firmware for leds and i2s
2025-06-19 Add: timers
2025-06-19 Fix: get all the basics running
    [Pikobeats.ino]
2025-06-19 Debug: still using the leds to test some state.
2025-06-20 Fix. both pitch shift and sample select working
    [Pikobeats.ino]
2025-06-20 Fix: remove core idling since it can crash.
    [Pikobeats.ino]
2025-06-20 Fix: move encoder processing and remove contention on leds to remove noise
    [Pikobeats.ino]
2025-06-20 Add: cv input to volume of current track, mode 0
2025-06-20 Fix: move jack in led signal to timer. cv also on slow timer.
    [Pikobeats.ino]
2025-06-26 Fix 3V3 missing on DAC and use additional LDO for 3V3 on DAC
    [pcb.kicad_pcb, pcb.kicad_sch]
2025-06-28 Fix: move DAC writes to 48khz timer and only do sample generation on request when dac has been writtern.
2025-06-28 Fix: new uf2 with latest timer code
2025-07-06 Rev 1.1
    [panel.kicad_pcb, pcb.kicad_pcb]
2025-07-23 Refactor: red/green duty cycles (red on by default, flipped in software).
    [Pikobeats.ino]
2025-07-24 Refactor: move led indicators to current channel
2025-07-29 fix: Allow rotational channel selection
    [Pikobeats.ino]
2025-12-08 Update: edited samples, all 16bit, 44khz
2025-12-10 Fix: set to 44100 kHz for pitch correct play, up buffer lengths
    [Pikobeats.ino]
2026-06-27 feat: rework audio engine, simplify UI, add CI
    Audio:
    - render on core1 paced by the I2S DMA buffer instead of a timer ISR
    - soft-clip the mix for headroom, precompute per-voice gain, ramp attacks
    - fix constrain() no-ops, the interpolation read past the sample end and
    the off-by-one LED and trigger loop bounds
    UI:
    - four encoder pages: select, sample, volume, pitch
    - per-channel LED colours with a 10s trigger-activity screensaver
    - save sample, pitch, volume and CV assignment to flash
    - encoder direction and sound kit are build-time options
    CI:
    - matrix build of every kit for normal and reversed encoders
    - release-please for versioning and releases
    [Pikobeats.ino]
2026-06-29 [Fix] remove the unused running average code since it is not applicable
    [Pikobeats.ino, seq.h]
2026-06-29 [Fix] remove unused encoder button tracking
    [Pikobeats.ino]
2026-07-01 ci: Cache arduino-cli core and libraries between runs
